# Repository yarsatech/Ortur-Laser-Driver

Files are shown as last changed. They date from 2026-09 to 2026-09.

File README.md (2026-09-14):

# Ortur Laser Driver PCB 

This is a homebrew PCB replacement for the LU2-4 LF laser module driver PCB used by ortur lasers.

## What does it look like.
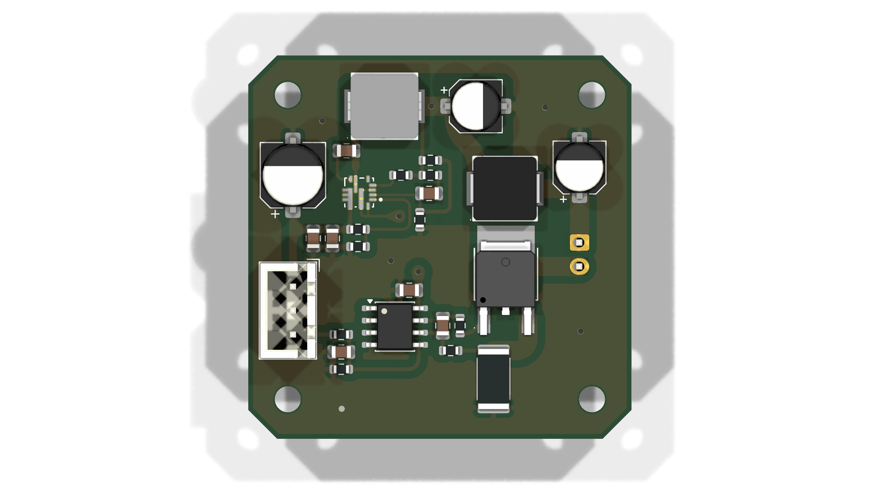
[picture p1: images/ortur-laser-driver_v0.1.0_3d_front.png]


## The schematic
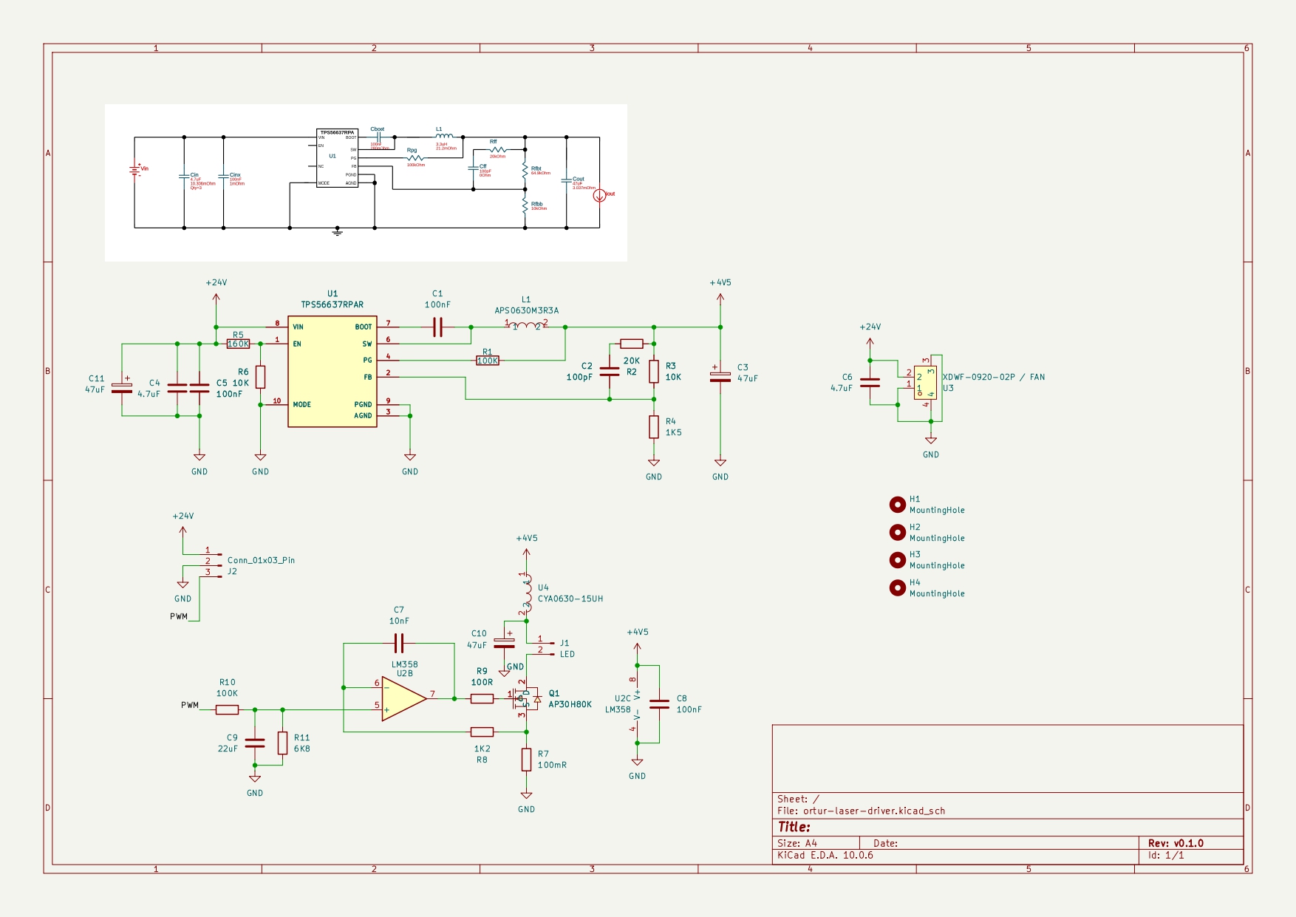
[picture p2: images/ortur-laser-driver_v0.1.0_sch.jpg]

You can find the schematic PDF and gerbers in the [releases](https://github.com/yarsatech/Ortur-Laser-Driver/releases).

## 
Hope this helps :)

Proudly designed and made in Nepal by Yarsa Tech.

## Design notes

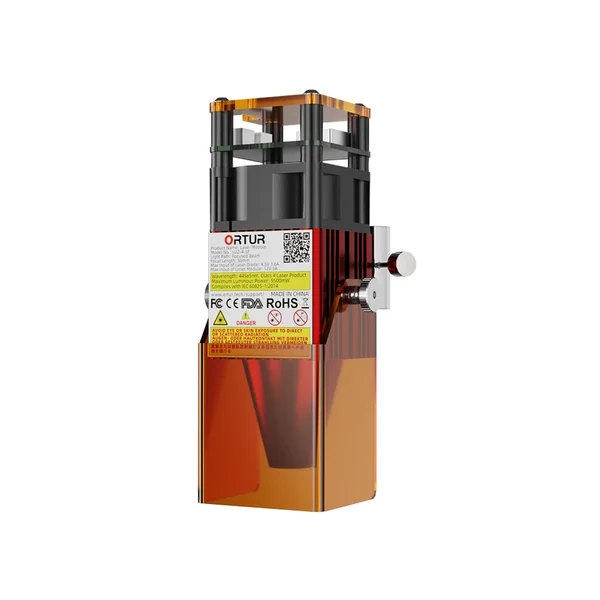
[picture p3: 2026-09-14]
images/laser-module.webp

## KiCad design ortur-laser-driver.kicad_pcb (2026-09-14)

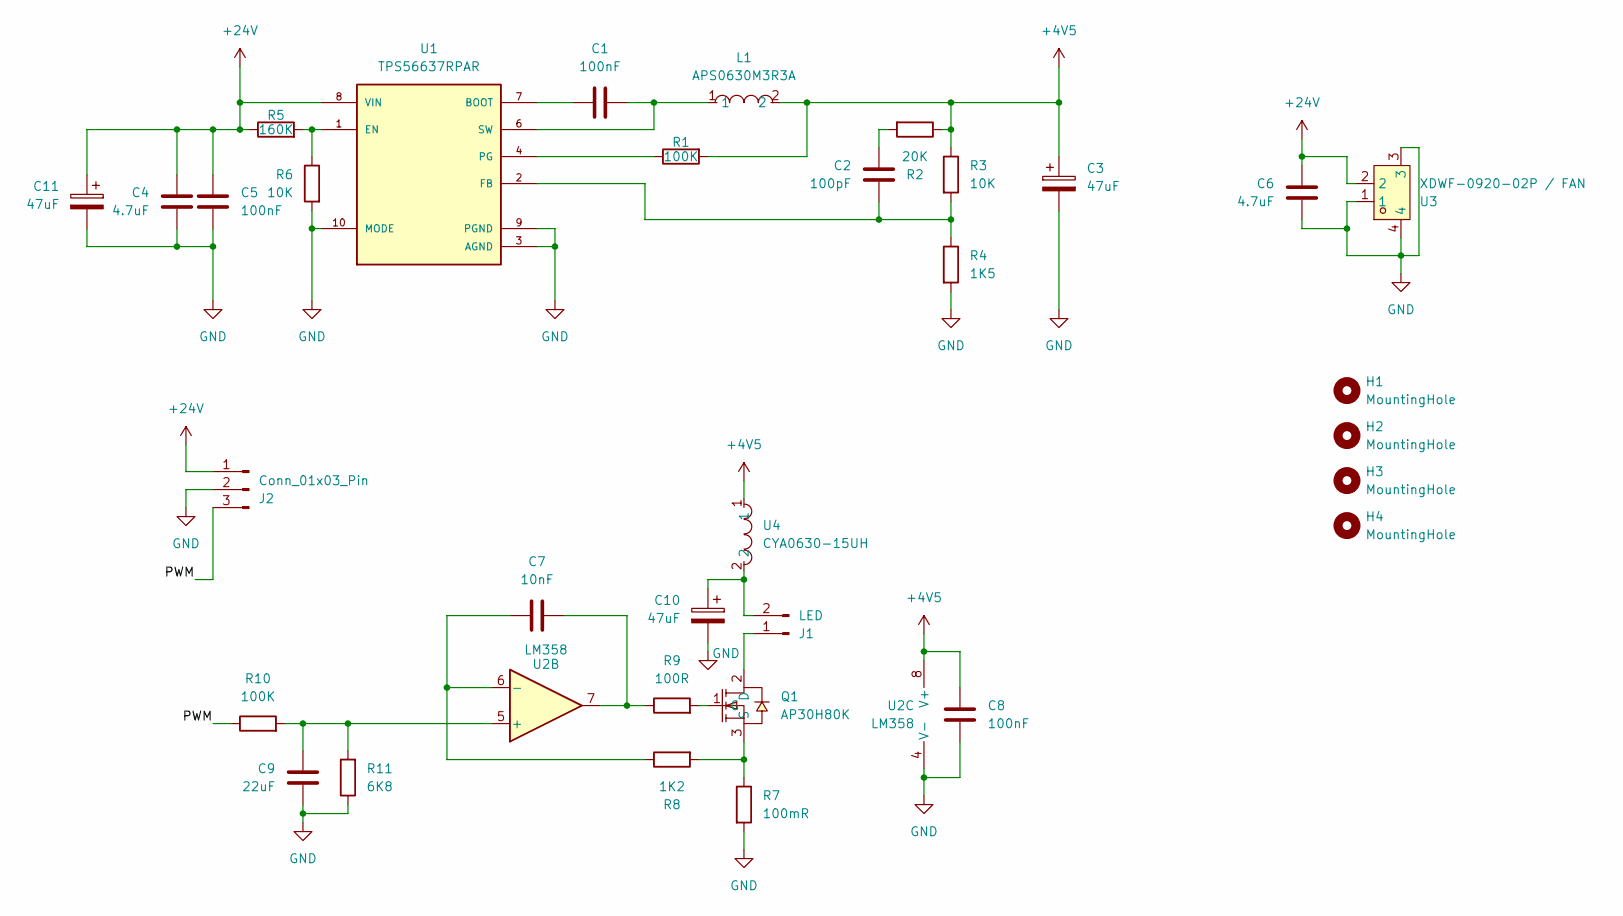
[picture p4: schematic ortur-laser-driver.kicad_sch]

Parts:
C1, C5, C8: 100nF; C_0805_2012Metric
C2: 100pF; C_0805_2012Metric
C3, C10: 47uF; CP_Elec_5x5.4
C4, C6: 4.7uF; C_0805_2012Metric
C7: 10nF; C_0805_2012Metric
C9: 22uF; C_0805_2012Metric
C11: 47uF; CP_Elec_6.3x7.7
H1, H2, H3, H4: MountingHole; MountingHole_2.7mm_M2.5
J1: LED; JST_EH_S2B-EH_1x02_P2.50mm_Horizontal
J2: Conn_01x03_Pin; JST_XH_B3B-XH-A_1x03_P2.50mm_Vertical
L1: APS0630M3R3A; IND-SMD_L7.7-W6.6_APS0630; MPN APS0630M3R3A; LCSC Part C47327202
Q1: AP30H80K; TO-252-2_L6.6-W6.1-P4.60-LS10.0-BR-CW; MPN AP30H80K; LCSC Part C2849564
R1, R10: 100K; R_0603_1608Metric
R2: 20K; R_0603_1608Metric
R3, R6: 10K; R_0603_1608Metric
R4: 1K5; R_0603_1608Metric
R5: 160K; R_0603_1608Metric
R7: 100mR; R_2512_6332Metric
R8: 1K2; R_0603_1608Metric
R9: 100R; R_0603_1608Metric
R11: 6K8; R_0603_1608Metric
U1: TPS56637RPAR; CONV_TPS56637RPAR; PARTREV A
U2: LM358; SOIC-8_3.9x4.9mm_P1.27mm
U3: XDWF-0920-02P / FAN; CONN-SMD_XDWF-0920-02P; MPN XDWF-0920-02P; LCSC Part C7527581
U4: CYA0630-15UH; IND-SMD_L7.2-W6.6_GPSR07X0; MPN CYA0630-15UH; LCSC Part C5189959

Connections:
+4V5: C3.1, C8.2, L1.2, R1.2, R2.1, R3.1, U2.8 (V+), U4.1
+24V: C4.2, C5.2, C6.2, C11.1, J2.1, R5.1, U1.8 (VIN), U3.2
/PWM: J2.3, R10.1
GND: C3.2, C4.1, C5.1, C6.1, C8.1, C9.1, C10.2, C11.2, J2.2, R4.2, R6.2, R7.2, R11.1, U1.3 (AGND), U1.9 (PGND), U1.10 (MODE), U2.4 (V-), U3.1, U3.3, U3.4
unnamed: C2.1, R2.2
unnamed: C7.1, R9.1, U2.7
unnamed: J1.1, Q1.2 (D)
unnamed: C10.1, J1.2, U4.2
unnamed: Q1.1 (G), R9.2
unnamed: Q1.3 (S), R7.1, R8.2
unnamed: C1.1, U1.7 (BOOT)
unnamed: R5.2, R6.1, U1.1 (EN)
unnamed: C2.2, R3.2, R4.1, U1.2 (FB)
unnamed: R1.1, U1.4 (PG)
unnamed: C1.2, L1.1, U1.6 (SW)
unnamed: C9.2, R10.2, R11.2, U2.5 (+)
unnamed: C7.2, R8.1, U2.6 (-)

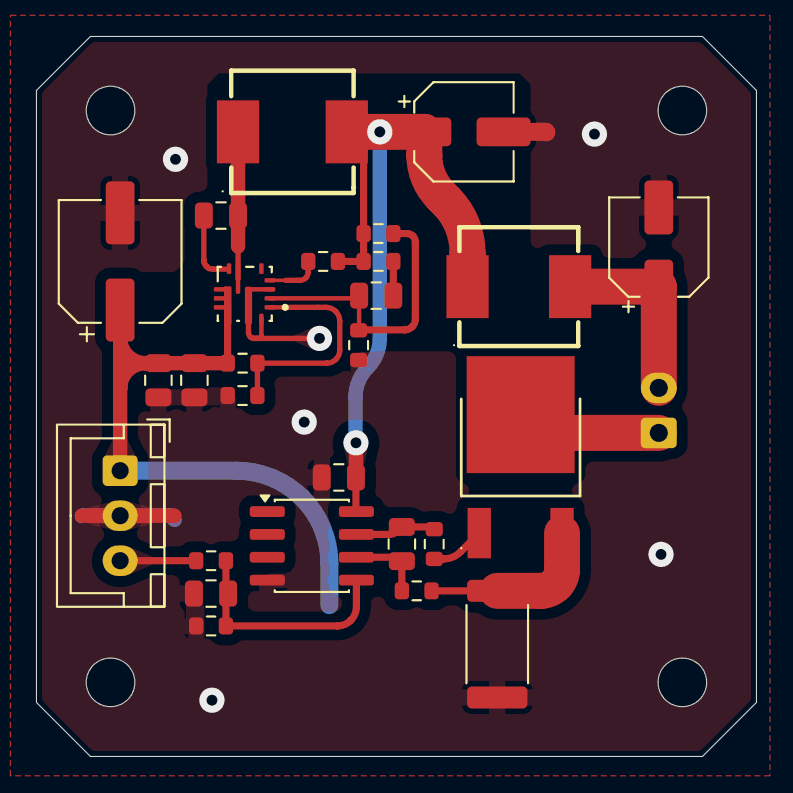
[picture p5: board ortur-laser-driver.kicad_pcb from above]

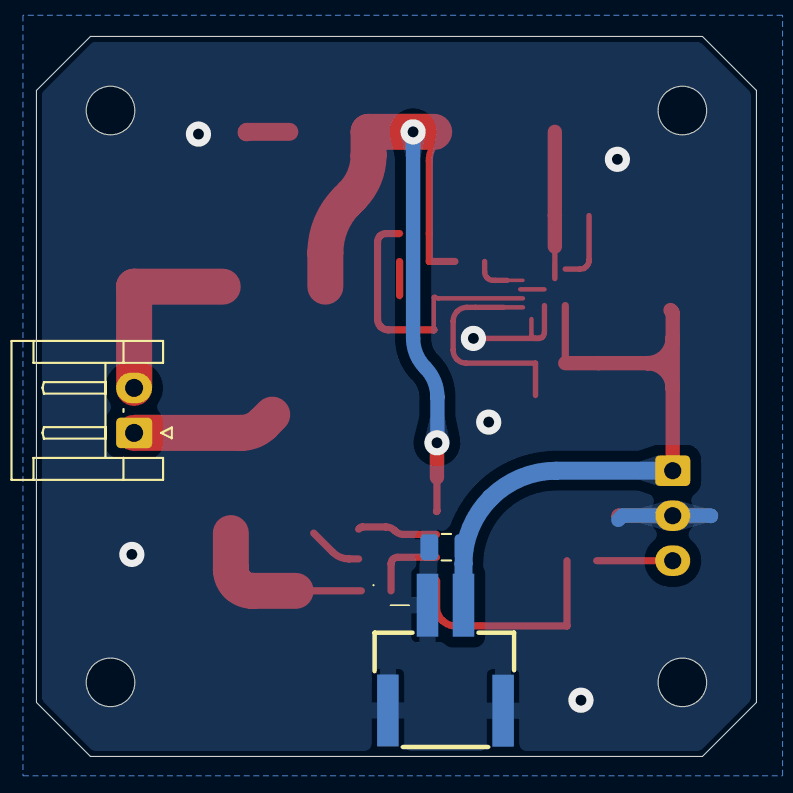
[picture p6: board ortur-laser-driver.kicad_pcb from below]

Board: 2 copper layers, 40.0 x 40.0 mm, 34 parts (3 on the bottom side), 17 nets.

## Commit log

2026-09-14 added readme; repo init
    [ortur-laser-driver.kicad_pcb, ortur-laser-driver.kicad_sch]
2026-09-14 updated workflows
    [ortur-laser-driver.kicad_pcb]
2026-09-14 fixed user
    [ortur-laser-driver.kicad_pcb]
